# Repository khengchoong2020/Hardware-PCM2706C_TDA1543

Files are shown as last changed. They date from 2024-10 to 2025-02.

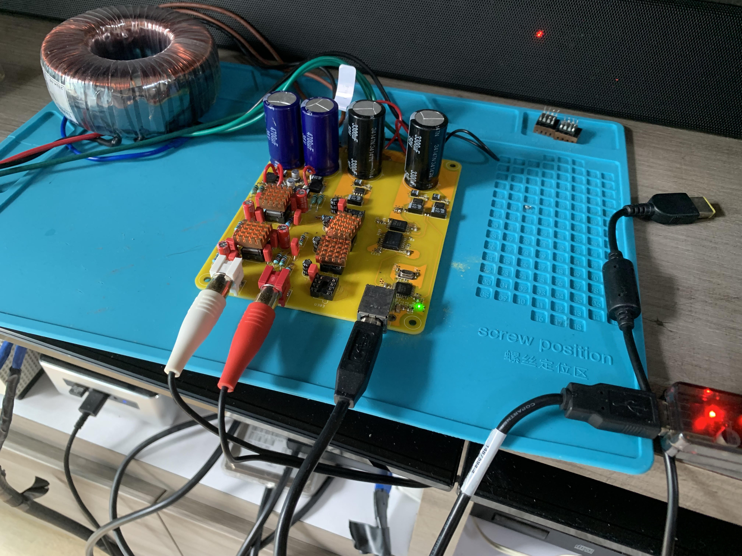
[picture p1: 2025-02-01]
PCM2706_TDA1543_SNE5532.jpg

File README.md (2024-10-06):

# Hardware-PCM2706C_TDA1543
PCM2706C and I2S NOS TDA1543 active current output
This is a Hardware project built on PM2706C, an TI USB to I2S converter to 4X TDA1543 (I2S version) NOS 16-bit audio DAC. The DAC output is built on active Op Amp (NE5532) for current-to-voltage conversion and 51KHz cut-off active filter with Op-Amp (NE5532).

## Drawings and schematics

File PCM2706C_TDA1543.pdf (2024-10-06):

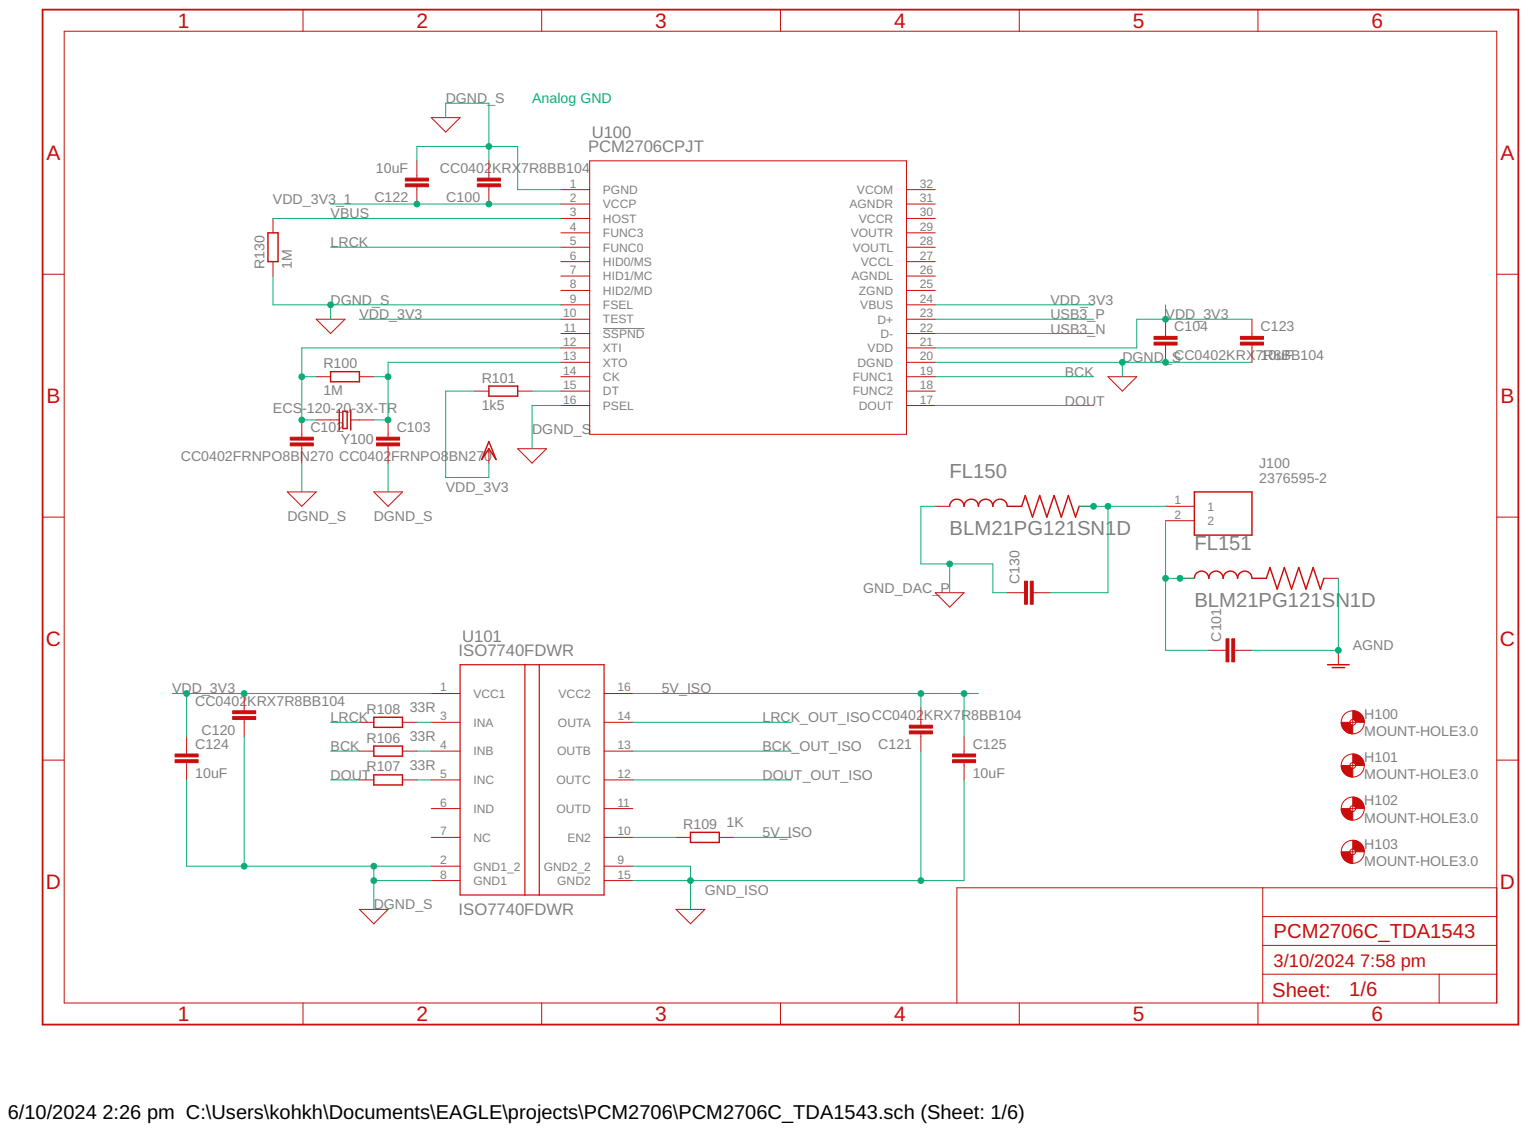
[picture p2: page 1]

6/10/2024 2:26 pm C:\Users\kohkh\Documents\EAGLE\projects\PCM2706\PCM2706C_TDA1543.sch (Sheet: 1/6)

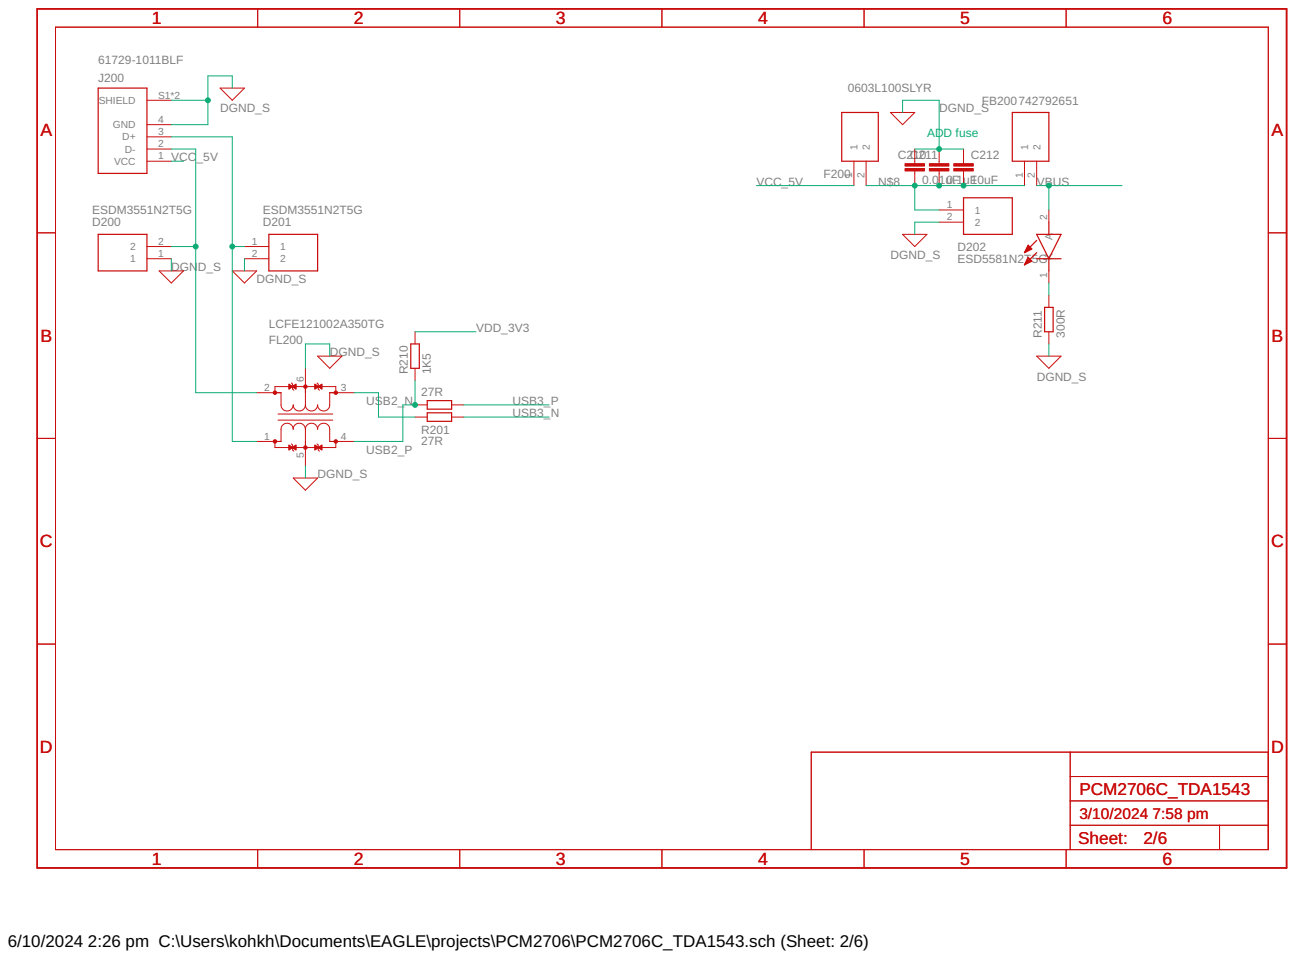
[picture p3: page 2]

6/10/2024 2:26 pm C:\Users\kohkh\Documents\EAGLE\projects\PCM2706\PCM2706C_TDA1543.sch (Sheet: 2/6)

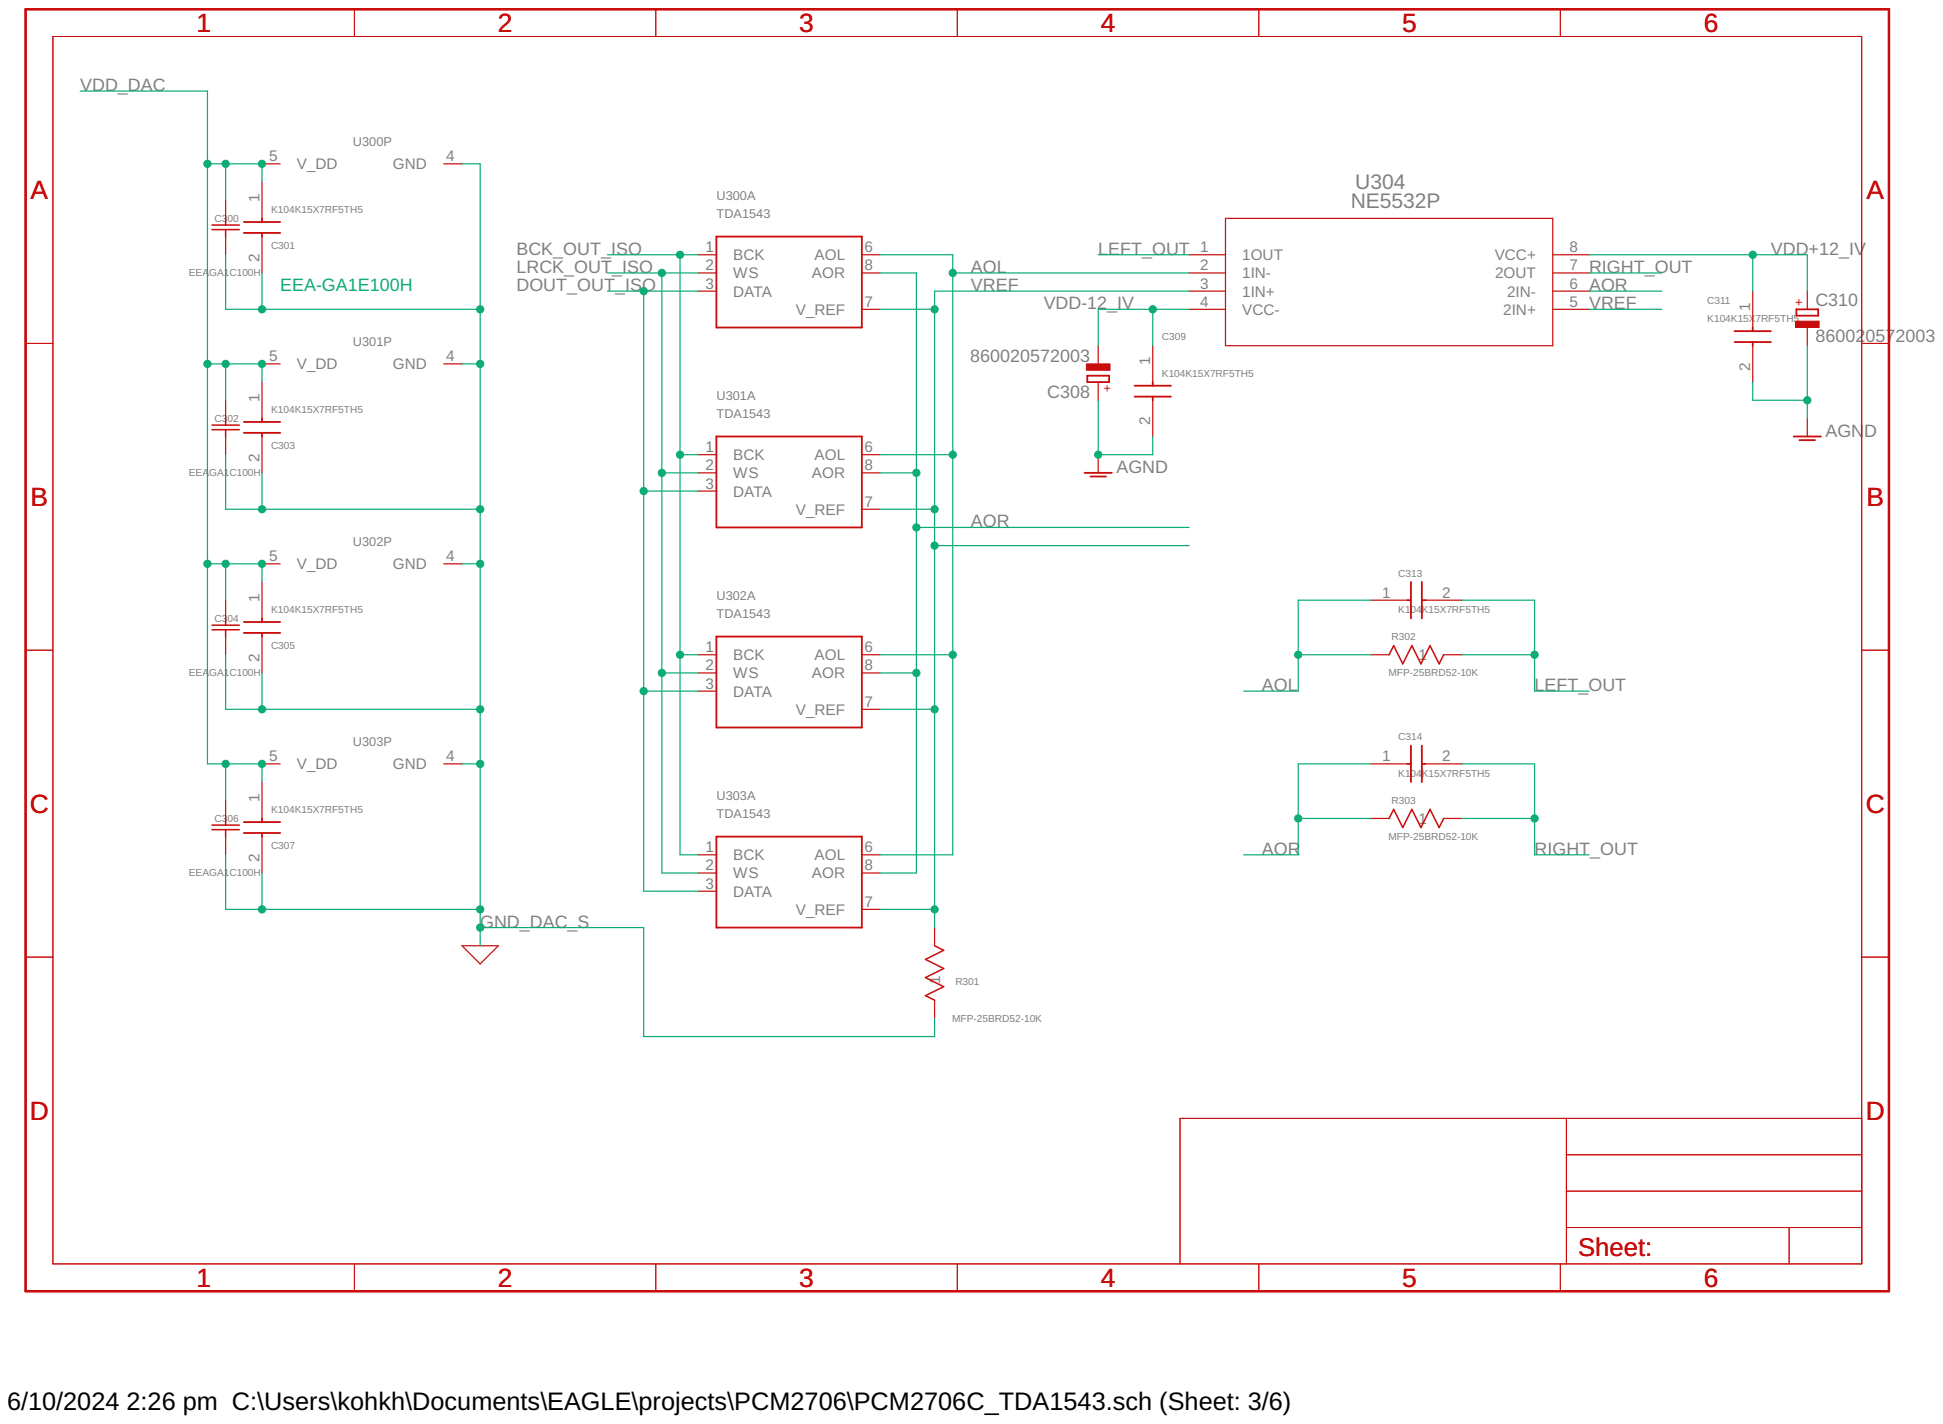
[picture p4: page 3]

1IN- 2 | 7 VCC+

3 | VCC- 4

6/10/2024 2:26 pm C:\Users\kohkh\Documents\EAGLE\projects\PCM2706\PCM2706C_TDA1543.sch (Sheet: 3/6)

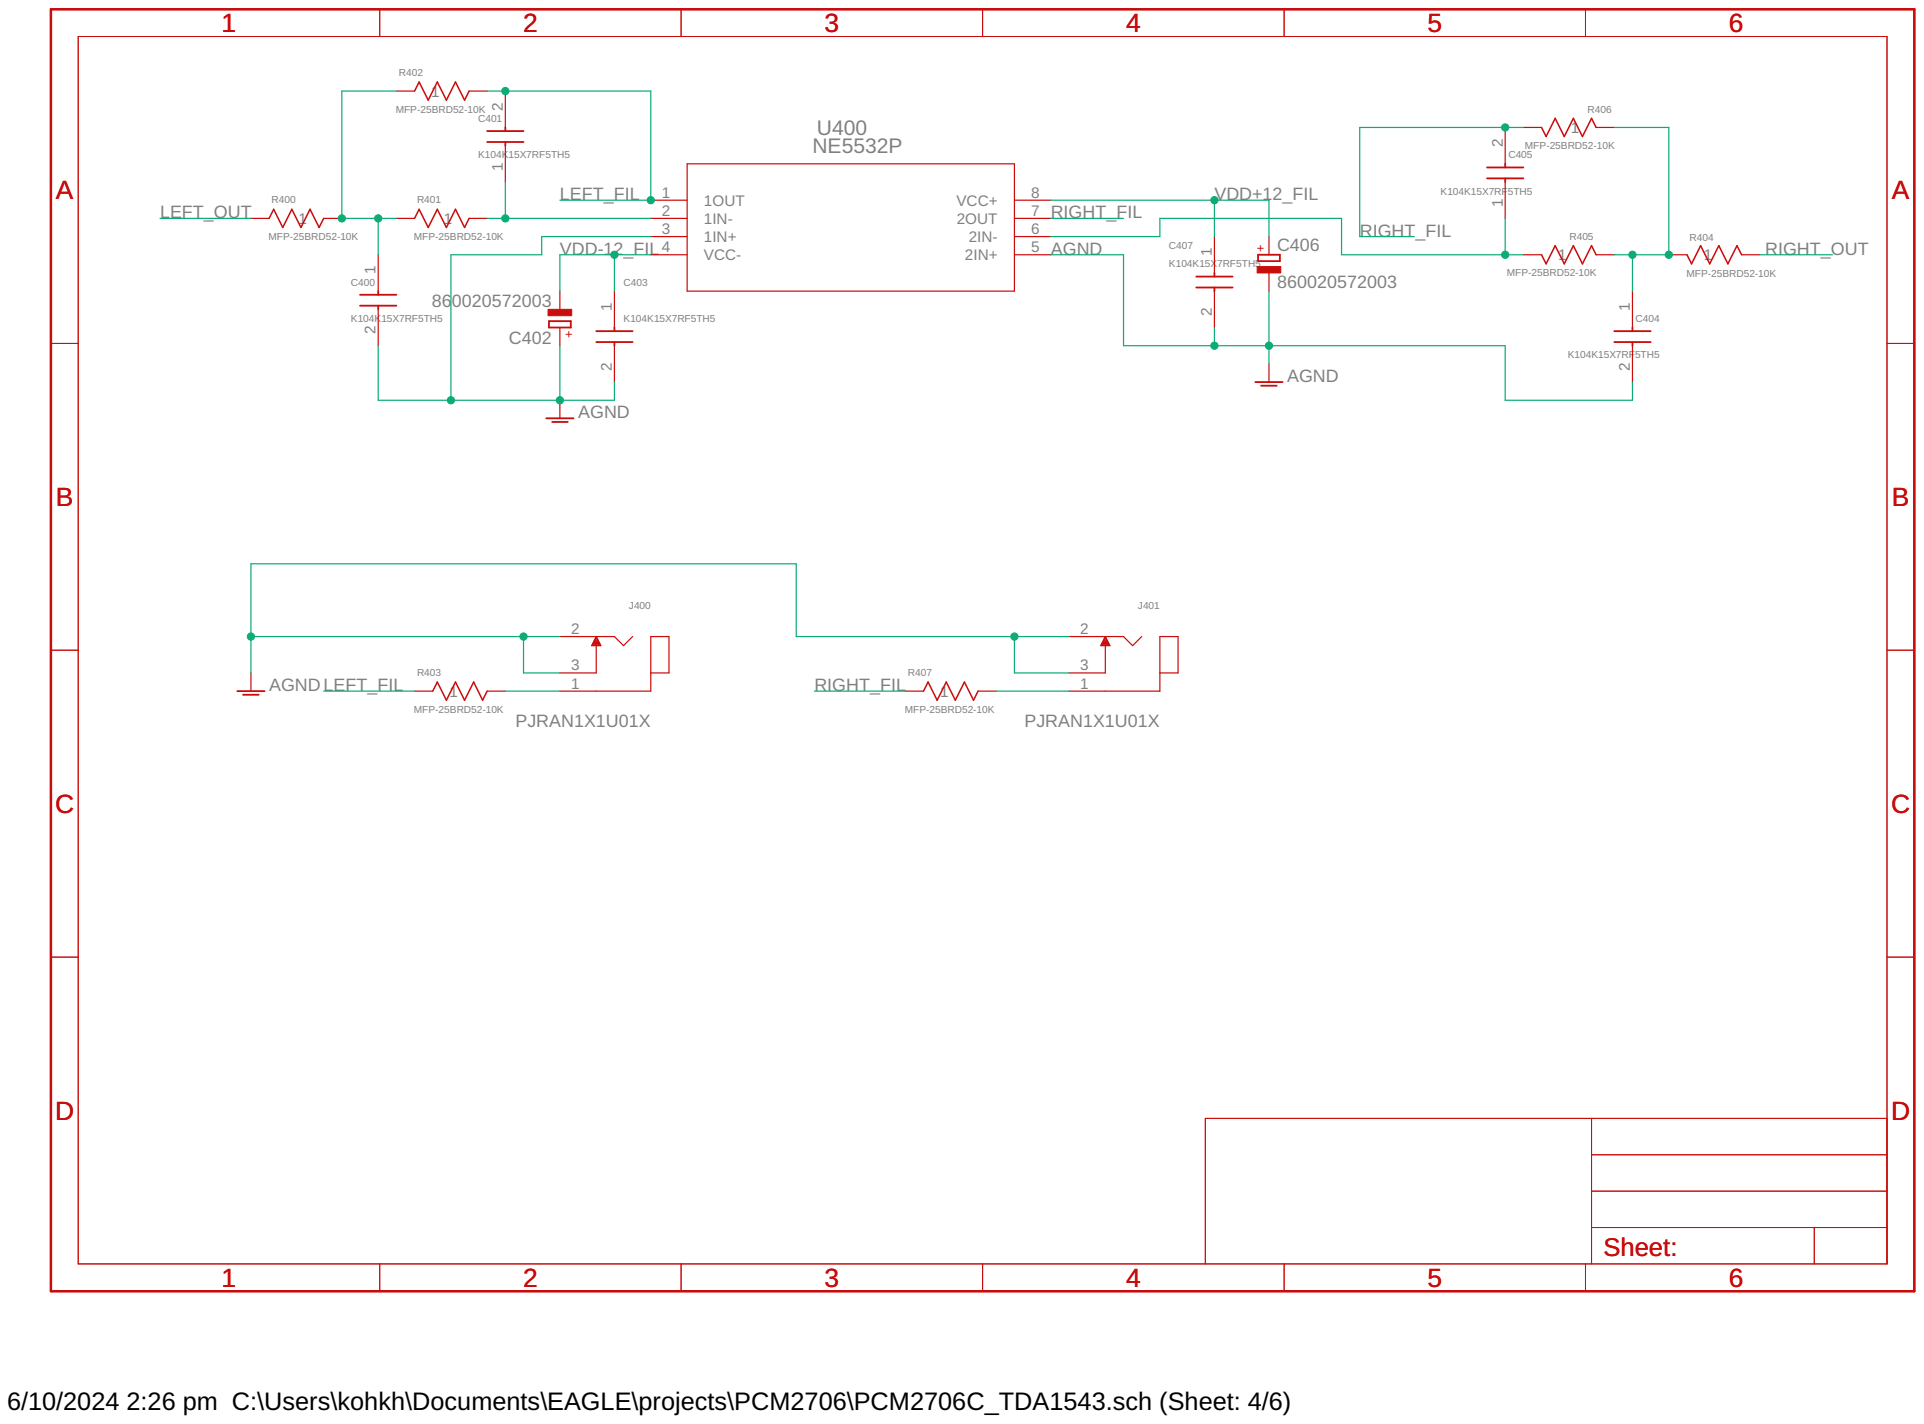
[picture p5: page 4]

6/10/2024 2:26 pm C:\Users\kohkh\Documents\EAGLE\projects\PCM2706\PCM2706C_TDA1543.sch (Sheet: 4/6)

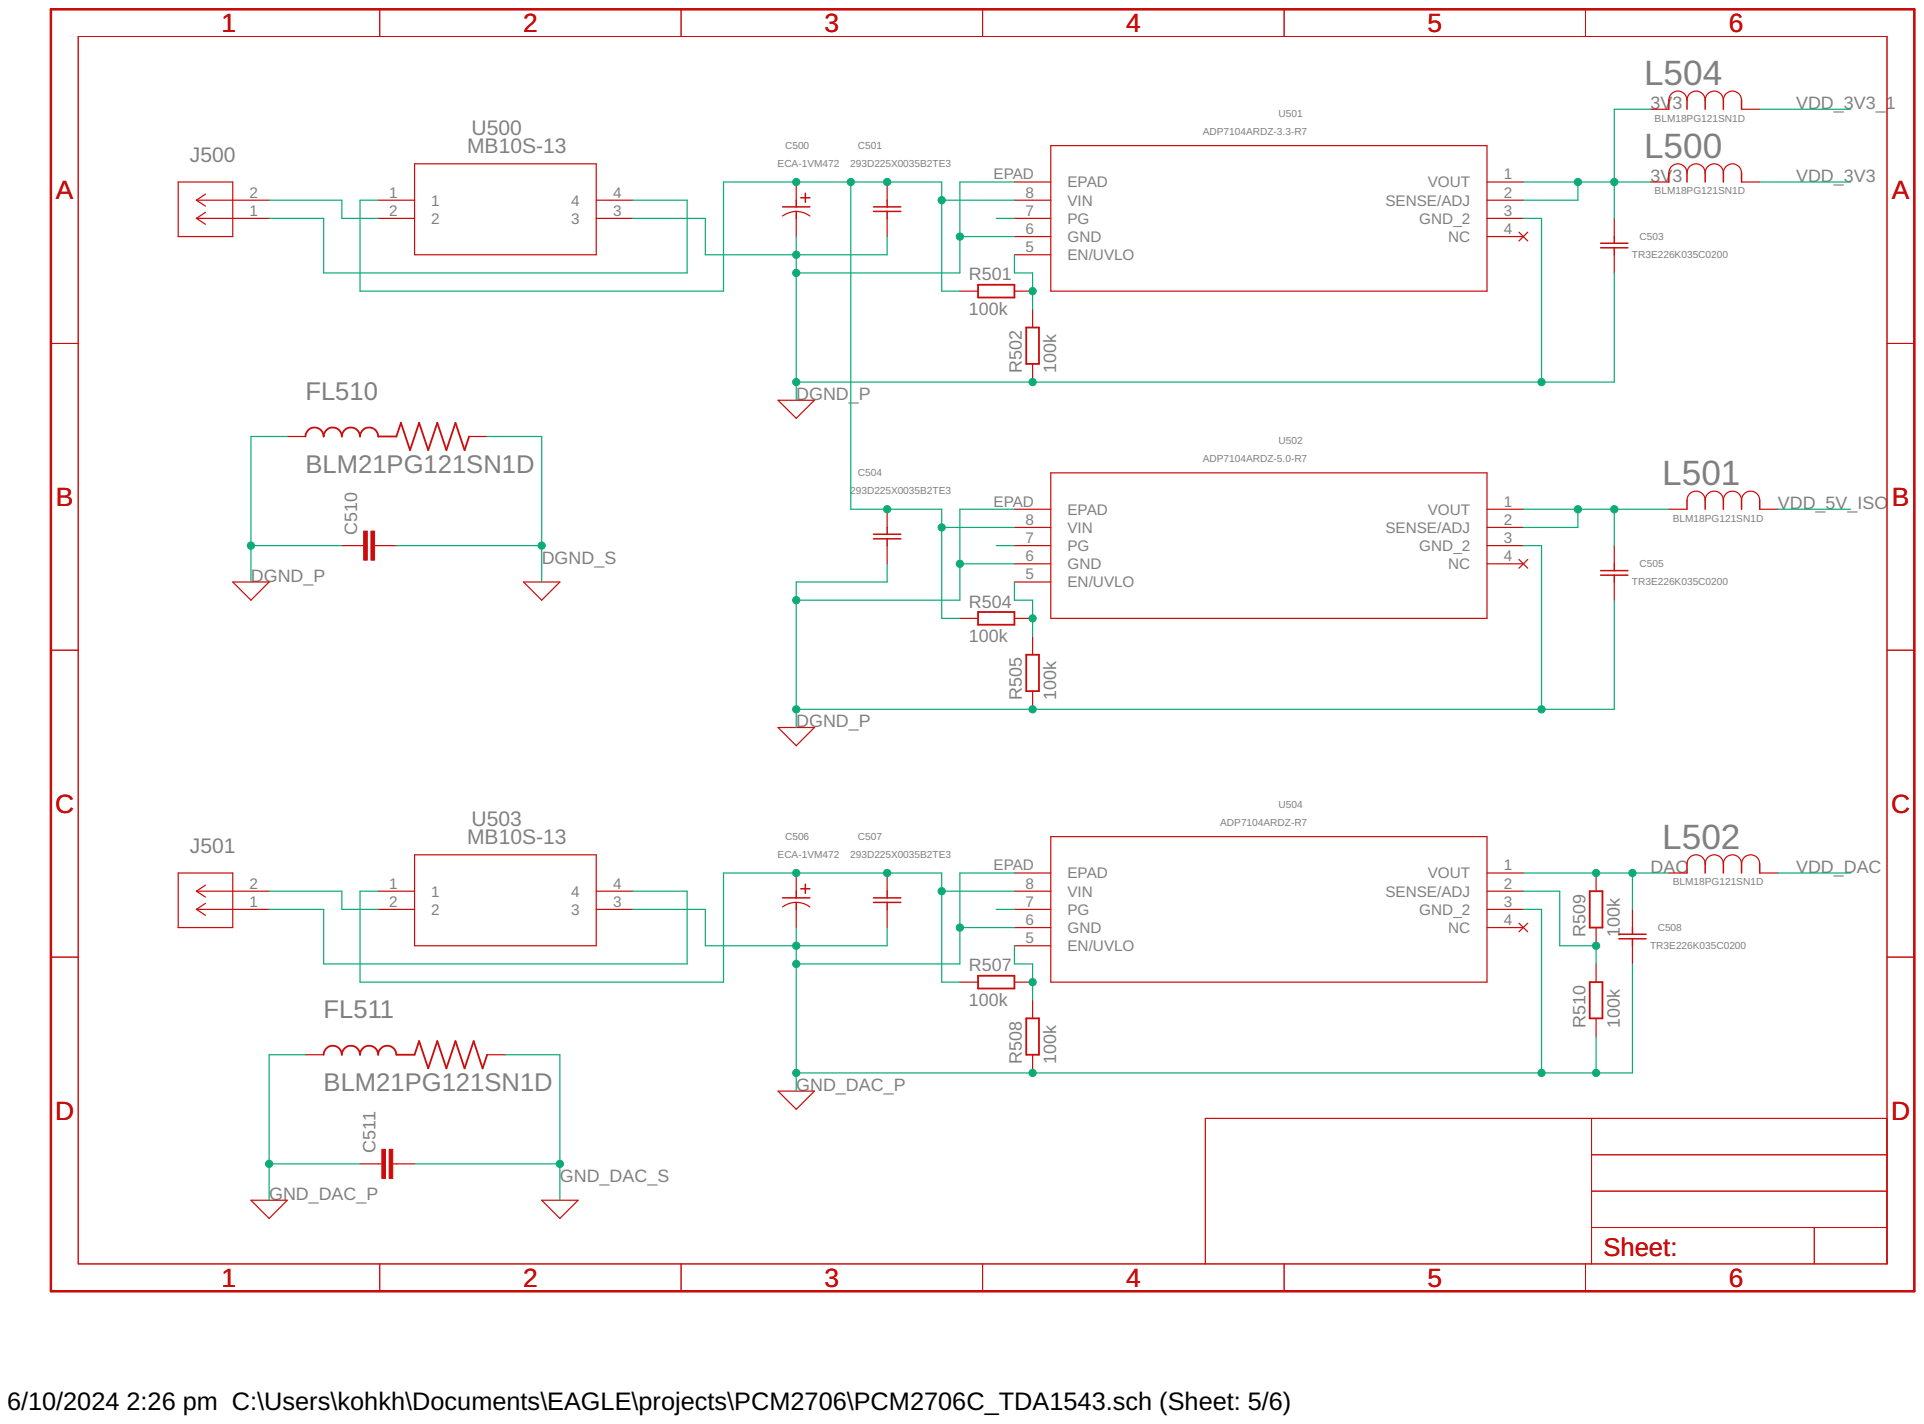
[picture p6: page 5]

6/10/2024 2:26 pm C:\Users\kohkh\Documents\EAGLE\projects\PCM2706\PCM2706C_TDA1543.sch (Sheet: 5/6)

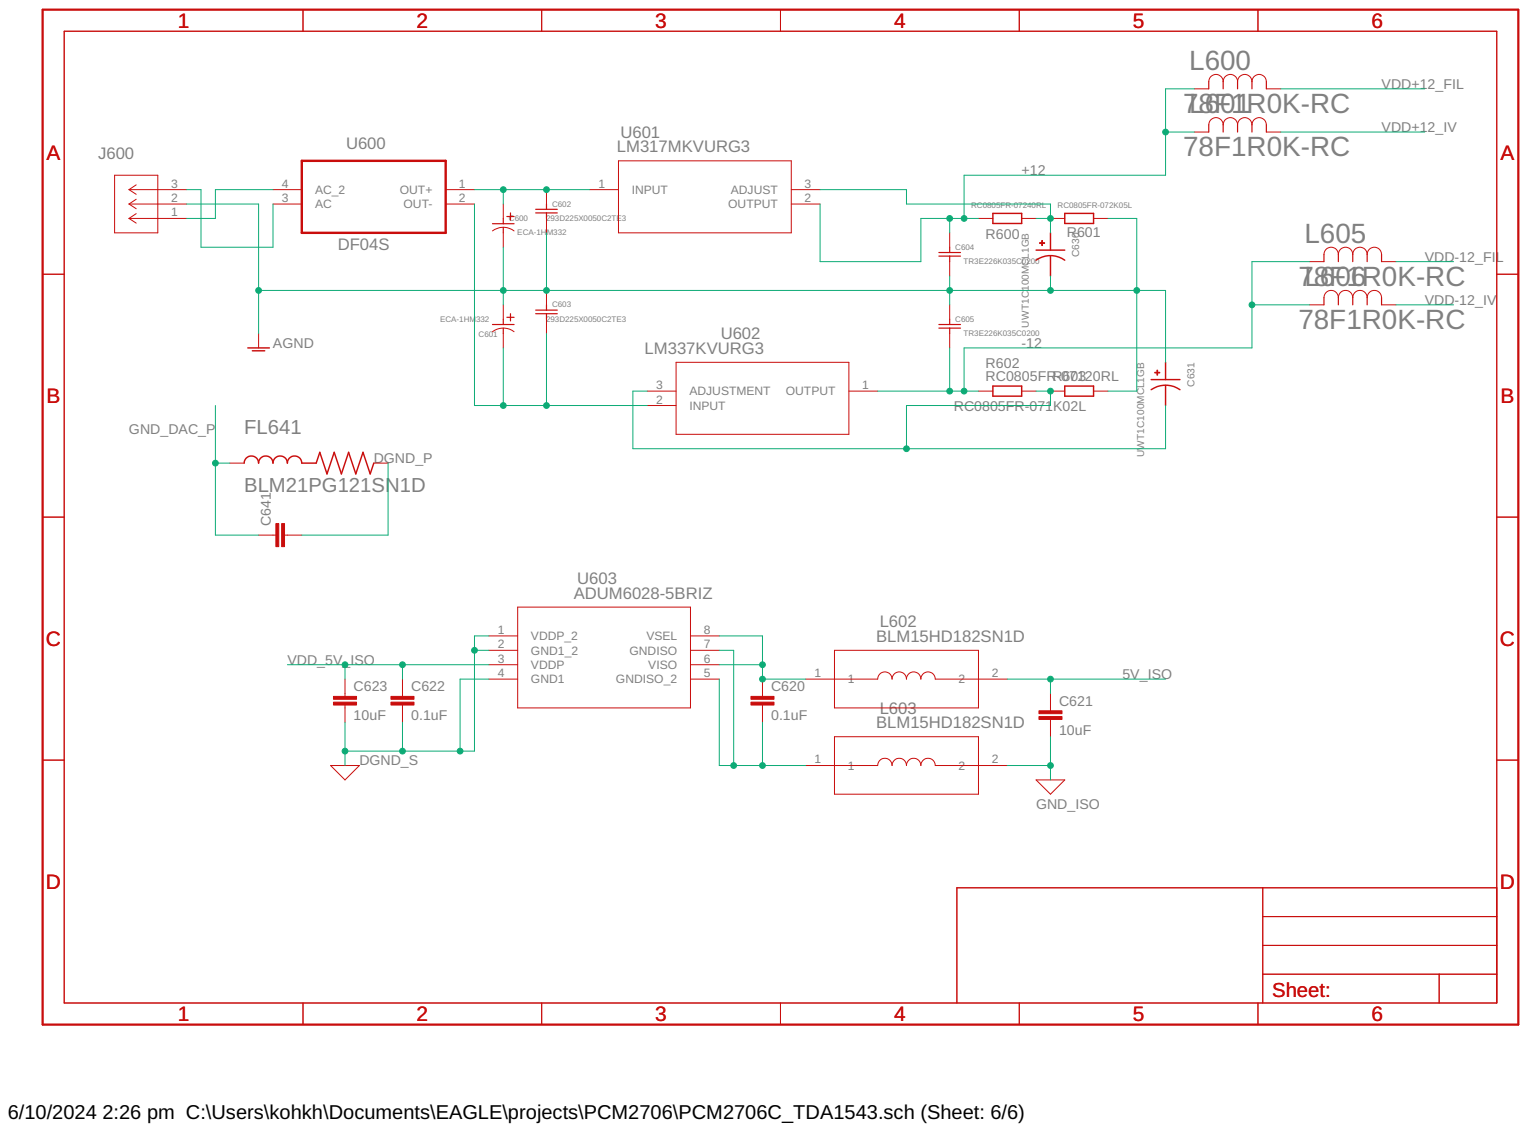
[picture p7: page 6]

6/10/2024 2:26 pm C:\Users\kohkh\Documents\EAGLE\projects\PCM2706\PCM2706C_TDA1543.sch (Sheet: 6/6)

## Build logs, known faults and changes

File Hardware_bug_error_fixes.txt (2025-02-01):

Hardware bug error fixes
1. Full wave bridge IC PCB part pin error, pin 2 and pin 4 swapped. lesson learned - must check pin during part import.
2. 18V to 12V 1A LDO regulator for analog opamp IC pin swapped.  lesson learned - must check pin during part import.
3. Separate ground for power plane and signal ground plane. From the sound does not seem to give any difference, will check with rightmark audio analyzer to check for signal to noise ratio. Does this ground separation yield a audio performance difference.
4. I2S signal isolator ground not tied to common signal ground which caused no I2S going to audio DAC. Does isolator ground has to tie to common digital ground ?
5. this 16 bit USB audio DAC uses PCM2706C as source from laptop, with I2S signal generated pass through digital isolator which works as level shifter as well as isolation between PCM2706C to TDA1543. the analog signal from TDA1543 passses to SNE5532 for I/V conversion 
and multifeeback LPF.
6. initial thought was to use 4 parallel TDA1543 which would increase SNR by 6dB, the theory of increasing the DAC by 2 fold would increase SNR by 3dB. One of TDA1543 generate chopper noise when inserted, suspected to be malfunction. The reolution was to make it 2 X TDA1543.
7. the sound was quiete impressive to my hearing, decent low,impresiive mid vocal, and noticeable high.
8. will try to fix the hardware bug and try 4 parallel if possible.
9. Both TDA1543 and opamp NSE5532 generate heats and heatsink are definitely a must. The DAC TDA1543s are biased at 5.5V, 0.5V above 5.0v. Iref resistor is 512R while I/V resistor is 543R, and the smoothing capacitor is 0.1nF (will change to 1nF or 3.3V)
10. Audio gain has to be investigated as i have to reduce foobar2k to almost 90dB and almost 20% of audio gain in linux machine.
11. Play tone file with no noticeable clipping when audio gain adjusted

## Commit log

2024-10-06 Add files via upload
    First commit
    PCM2706C ,an USB to I2S audio converter project to 4xTDA1543 (I2S) version an active Op Amp IV and Op Amp filter
    [PCM2706C_TDA1543.brd]
2024-10-06 Add files via upload
    added more schematic pages
